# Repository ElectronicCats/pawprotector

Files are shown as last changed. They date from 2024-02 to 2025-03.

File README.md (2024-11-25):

# Paw Protector

The **Paw Protector** by **Electronic Cats** is a device specifically designed to protect the USB port of electronic devices, such as smartphones and tablets, when used in environments at risk of malicious devices like keyloggers or physical damage from devices like USB Killers. This accessory acts as a "physical fuse" that prevents data exchange and only allows power transmission, negotiating with the host device to achieve the maximum possible charging power.

### Key Features:
- **Compact and lightweight design:** Easy to install in any setup without taking up extra space.  
- **Universal compatibility:** Works with a wide range of devices with USB ports.  
- **Damage prevention:** Reduces the risk of malicious devices and physical threats to USB ports.  

- Attach between your USB cable and charger to physically block data transfer / syncing. Charge mobile devices without any pop-ups or risk of hacking / downloading viruses in cars, airports etc
- Our SmartCharge chip automatically switches between Apple, Universal and Samsung standards to ensure compatibility with your device and charge at up to 2.4A
- This is our USB-A to A model.
- Paw Protector protects your mobile data from being accidentally shared, stolen, or infected with malware! Paw Protector only transfers power, not your privacy!
- Completely open source

<p align=center>
<a href="https://electroniccats.com/store/paw-protector/">
  
</a>
<a href="https://github.com/ElectronicCats/pawprotector/wiki">
  
</a>
</p>

<p align=center>
Also available at distributors:
</p>
<p align=center>
<a href="https://labs.ksec.co.uk/product-category/electronic-cat/">

</a>
</p>

## Wiki

For more details, please see the [Wiki](https://github.com/ElectronicCats/pawprotector/wiki) section.

## How to contribute 
 Contributions are welcome! 

Please read the document  [**Contribution Manual**](https://github.com/ElectronicCats/electroniccats-cla/blob/main/electroniccats-contribution-manual.md)  which will show you how to contribute your changes to the project.

✨ Thanks to all our [contributors](https://github.com/ElectronicCats/Cat-Sink/graphs/contributors)! ✨

See [**_Electronic Cats CLA_**](https://github.com/ElectronicCats/electroniccats-cla/blob/main/electroniccats-cla.md) for more information.

See the  [**community code of conduct**](https://github.com/ElectronicCats/electroniccats-cla/blob/main/electroniccats-community-code-of-conduct.md) for a vision of the community we want to build and what we expect from it."			

## License

OpenSourceLicense

Electronic Cats invests time and resources providing this open source design, please support Electronic Cats and open-source hardware by purchasing products from Electronic Cats!

Designed by Electronic Cats.

Firmware released under an GNU AGPL v3.0 license. See the LICENSE file for more information.

Hardware released under an CERN Open Hardware Licence v1.2. See the [LICENSE_HARDWARE](https://github.com/ElectronicCats/pawprotector/blob/main/LICENSE_HARDWARE.md) file for more information.

Electronic Cats is a registered trademark, please do not use it if you sell these PCBs.

Jul 2023
 
## Maintainer

<a
href="https://github.com/sponsors/ElectronicCats">



</a>

Electronic Cats invests time and resources providing this open source design, please support Electronic Cats and open-source hardware by purchasing products from Electronic Cats!

[Agregando el link como referencia]: <https://github.com/ElectronicCats/Template-Project-KiCAD-CI>

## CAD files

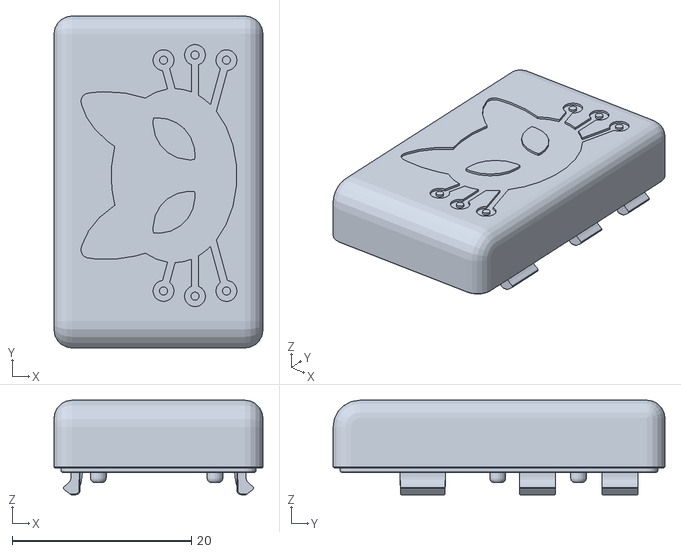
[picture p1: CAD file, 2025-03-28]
case/PART_A-PAW PROTECTOR_CASE.stl
23.3 x 37.0 x 10.5

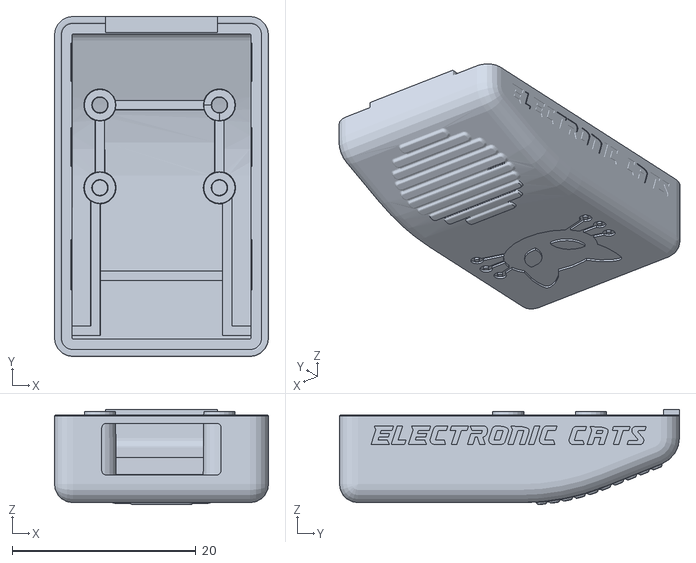
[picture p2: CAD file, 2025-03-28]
case/PART_B-PAW PROTECTOR_CASE.stl
23.3 x 37.0 x 10.4

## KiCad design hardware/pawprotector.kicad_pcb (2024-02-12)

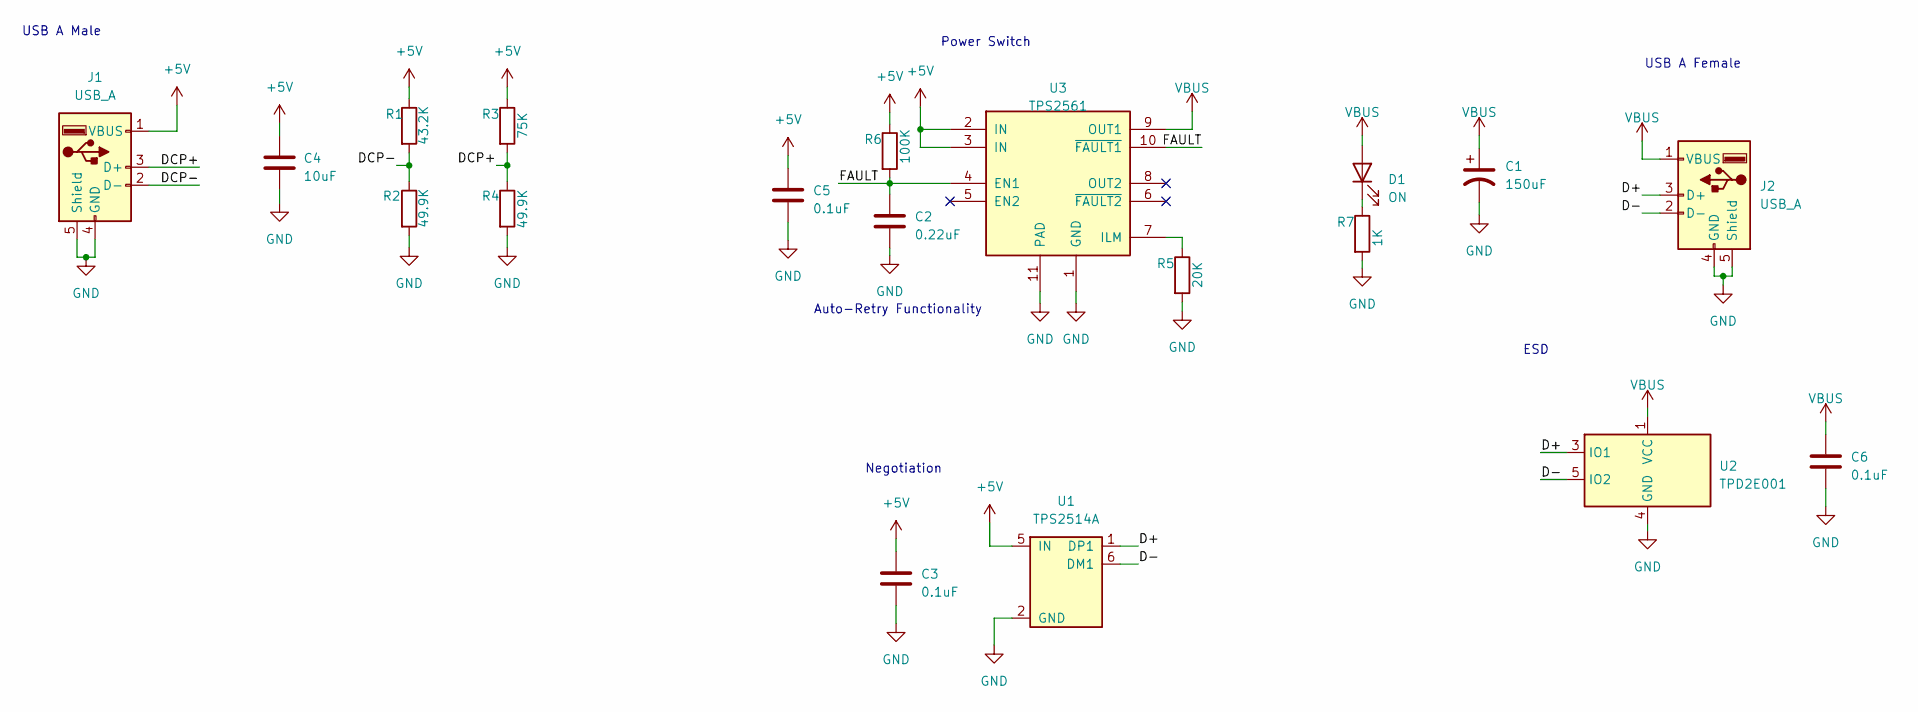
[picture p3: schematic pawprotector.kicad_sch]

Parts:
C1: 150uF; CP_Elec_6.3x5.4; LCSC# C2895744
C2: 0.22uF; C_0402_1005Metric; LCSC# C576742
C3, C5, C6: 0.1uF; C_0402_1005Metric; LCSC# C392963
C4: 10uF; C_0805_2012Metric; LCSC# C3015160
D1: ON; LED_0402_1005Metric; LCSC# C965790
J1: USB_A; C46394; LCSC# C46394
J2: USB_A; 875832010BLF; LCSC# C599118
R1: 43.2K; R_0402_1005Metric; LCSC# C2906870
R2, R4: 49.9K; R_0402_1005Metric; LCSC# C2906873
R3: 75K; R_0402_1005Metric; LCSC# C328330
R5: 20K; R_0402_1005Metric; LCSC# C100292
R6: 100K; R_0402_1005Metric; LCSC# C284273
R7: 1K; R_0402_1005Metric; LCSC# C2935237
U1: TPS2514A; SOT-23-6; LCSC# C157567
U2: TPD2E001; SOT-553; LCSC# C150526
U3: TPS2561; VSON-10-1EP_3x3mm_P0.5mm_EP1.65x2.4mm_ThermalVias

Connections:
+5V: C3.1, C4.1, C5.1, J1.1 (VBUS), R1.1, R3.1, R6.1, U1.5 (IN), U3.2 (IN), U3.3 (IN)
/D+: J2.3 (D+), U1.1 (DP1), U2.3 (IO1)
/D-: J2.2 (D-), U1.6 (DM1), U2.5 (IO2)
/DCP+: J1.3 (D+), R3.2, R4.1
/DCP-: J1.2 (D-), R1.2, R2.1
/FAULT: C2.1, R6.2, U3.4 (EN1), U3.10 (~FAULT1)
GND: C1.2, C2.2, C3.2, C4.2, C5.2, C6.2, J1.4 (GND), J1.5 (Shield), J2.4 (GND), J2.5 (Shield), R2.2, R4.2, R5.2, R7.2, U1.2 (GND), U2.4 (GND), U3.1 (GND), U3.11 (PAD)
unnamed: D1.1 (K), R7.1
unnamed: R5.1, U3.7 (ILM)
VBUS: C1.1, C6.1, D1.2 (A), J2.1 (VBUS), U2.1 (VCC), U3.9 (OUT1)

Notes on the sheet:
USB A Female
Power Switch
Auto-Retry Functionality
ESD
Negotiation
USB A Male

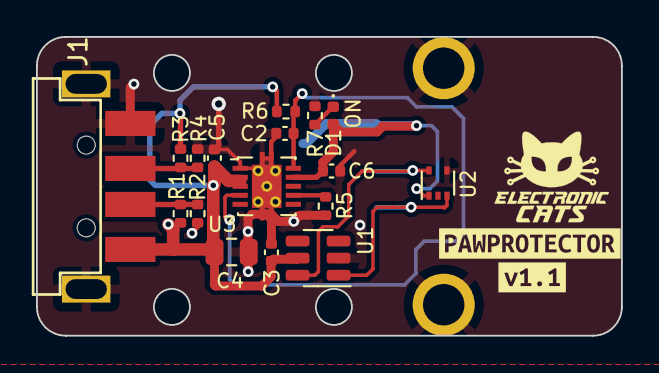
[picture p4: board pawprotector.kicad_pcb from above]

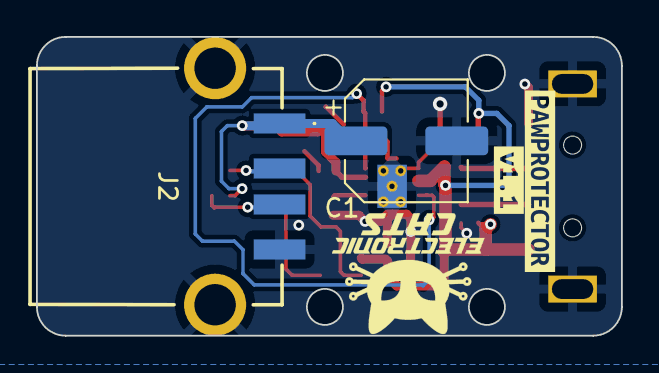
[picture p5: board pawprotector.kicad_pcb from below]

Board: 2 copper layers, 32.5 x 16.6 mm, 23 parts (4 on the bottom side), 10 nets.

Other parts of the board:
kibuzzard-65CAA4BB: G***; kibuzzard-65CAA4BB
kibuzzard-65CAA4FF: G***; kibuzzard-65CAA4FF
kibuzzard-65CAA527: G***; kibuzzard-65CAA527
kibuzzard-65CAA533: G***; kibuzzard-65CAA533

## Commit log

2023-02-01 First schematic from USB A to USB A
    [USB_condom.kicad_pcb, USB_condom.kicad_sch]
2023-03-27 Usb a-a, usb a-b upgrade
    Last update of the USB condom
    [CUSBa_a.kicad_sch, CUSBa_b.kicad_sch, USB_condom.kicad_sch]
2023-04-19 update project add schematic and first layout
    [USB_condom.kicad_pcb, USB_condom.kicad_sch]
2023-04-19 update labels
    [USB_condom.kicad_pcb]
2023-04-19 remove others files
    [CUSBa_a.kicad_sch, CUSBa_b.kicad_sch]
2023-04-20 add capacitor, add LCSC numbers
    [USB_condom.kicad_pcb, USB_condom.kicad_sch]
2023-04-20 update pcb
    [USB_condom.kicad_pcb]
2024-01-10 Pawprotector.step generated
    [USB_condom.kicad_pcb]
2024-02-19 BOM updated
    [USB_condom.kicad_sch]
2024-02-20 rename project
    [pawprotector.kicad_pcb, pawprotector.kicad_sch]
2024-04-24 feat(docs): add distributor button
2024-04-24 feat(docs): add text and distributor button
2025-03-28 feat(hw): case files
    [PART_A-PAW PROTECTOR_CASE.stl, PART_B-PAW PROTECTOR_CASE.stl]
2026-10-12 docs: distributors button in the same style as the store and wiki buttons
2026-10-12 docs: distributors button with the same rounded typeface as the other buttons
2026-10-12 docs: a heading above the button row so the images read as links
